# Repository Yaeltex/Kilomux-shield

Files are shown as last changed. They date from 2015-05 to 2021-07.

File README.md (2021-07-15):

# Kilomux Shield
This is the Kilomux Arduino Shield repository, developed by Yaeltex in collaboration with Jorge Crowe from El Laboratorio del Juguete, both located in Buenos Aires, Argentina.

Kilomux is an Arduino UNO shield which expands the number of inputs and outputs using multiplexers and 74HC595 ICs and allows MIDI communication via USB or hardware.

Kilomux Arduino Library has a [new repo](https://github.com/Yaeltex/kilomux-arduino-library) now!

It has 16 digital outputs (without PWM for the moment) and 32 analog/digital inputs, which can be used independently with the provided functions. 
The shield has also 4 free digital pins (2, 3, 12 and 13 in v1, and 10, 11, 12 and 13 in v2), intended to connect an ultrasonic sensor, a button and an LED for its activation.

In the repository you can find whole HIDUINO repository - the firmware to send MIDI via USB and allow PC to recognize the Arduino as a MIDI device. In the "hiduino-master" folder you can find a tutorial on how to recompile (and rename) the firmware and load it into the Arduino device.

For more info, go to our [wiki](https://wiki.yaeltex.com/?nocache=1#.C2.B7_Kilomux_Shield) (in Spanish, for now)

If you have any questions, suggestions or comments about the shield, email us at franco (at) yaeltex.com.ar or post in [Yaeltex's forum](http://forum.yaeltex.com)

Cheers!

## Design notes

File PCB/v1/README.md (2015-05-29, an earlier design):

Para ver la lista de materiales entra al siguiente enlace:

https://cdn.rawgit.com/Yaeltex/KiloMux-Shield/master/PCB/KILO_MUX_SHIELD%20v1_bom.html

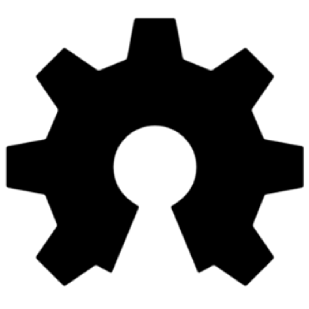
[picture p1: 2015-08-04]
PCB/v2/IMG serigrafia/OSH.bmp

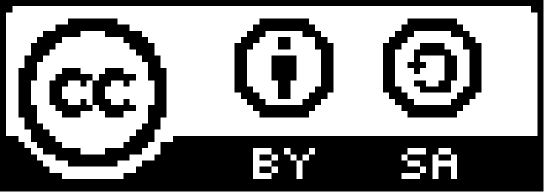
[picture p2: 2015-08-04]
PCB/v2/IMG serigrafia/CC-BY-SA bw2.bmp

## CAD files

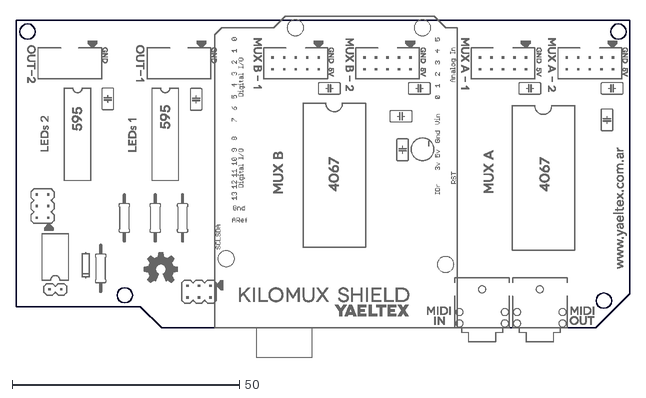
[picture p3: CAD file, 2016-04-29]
PCB/v2/Eagle/KilomuxV2.dxf
135.0 x 75.1

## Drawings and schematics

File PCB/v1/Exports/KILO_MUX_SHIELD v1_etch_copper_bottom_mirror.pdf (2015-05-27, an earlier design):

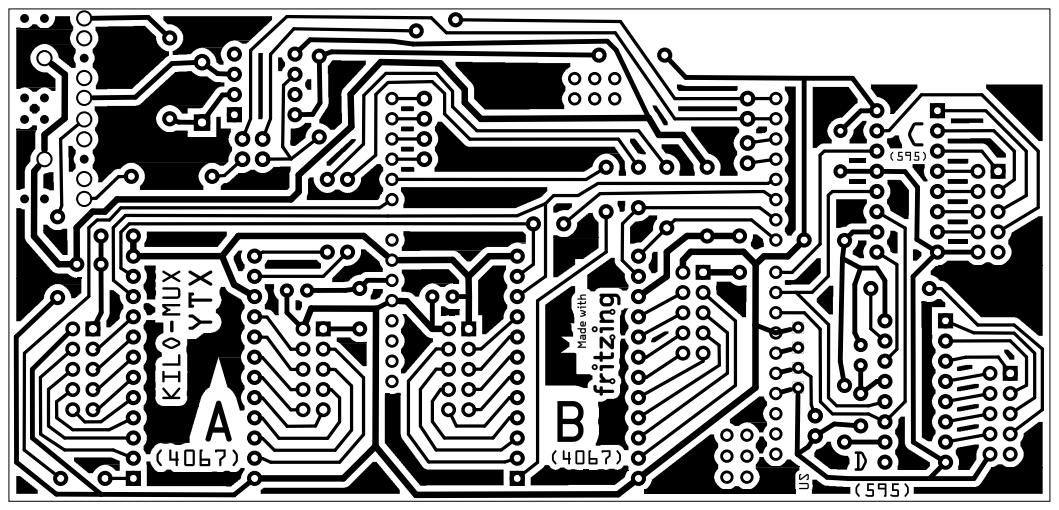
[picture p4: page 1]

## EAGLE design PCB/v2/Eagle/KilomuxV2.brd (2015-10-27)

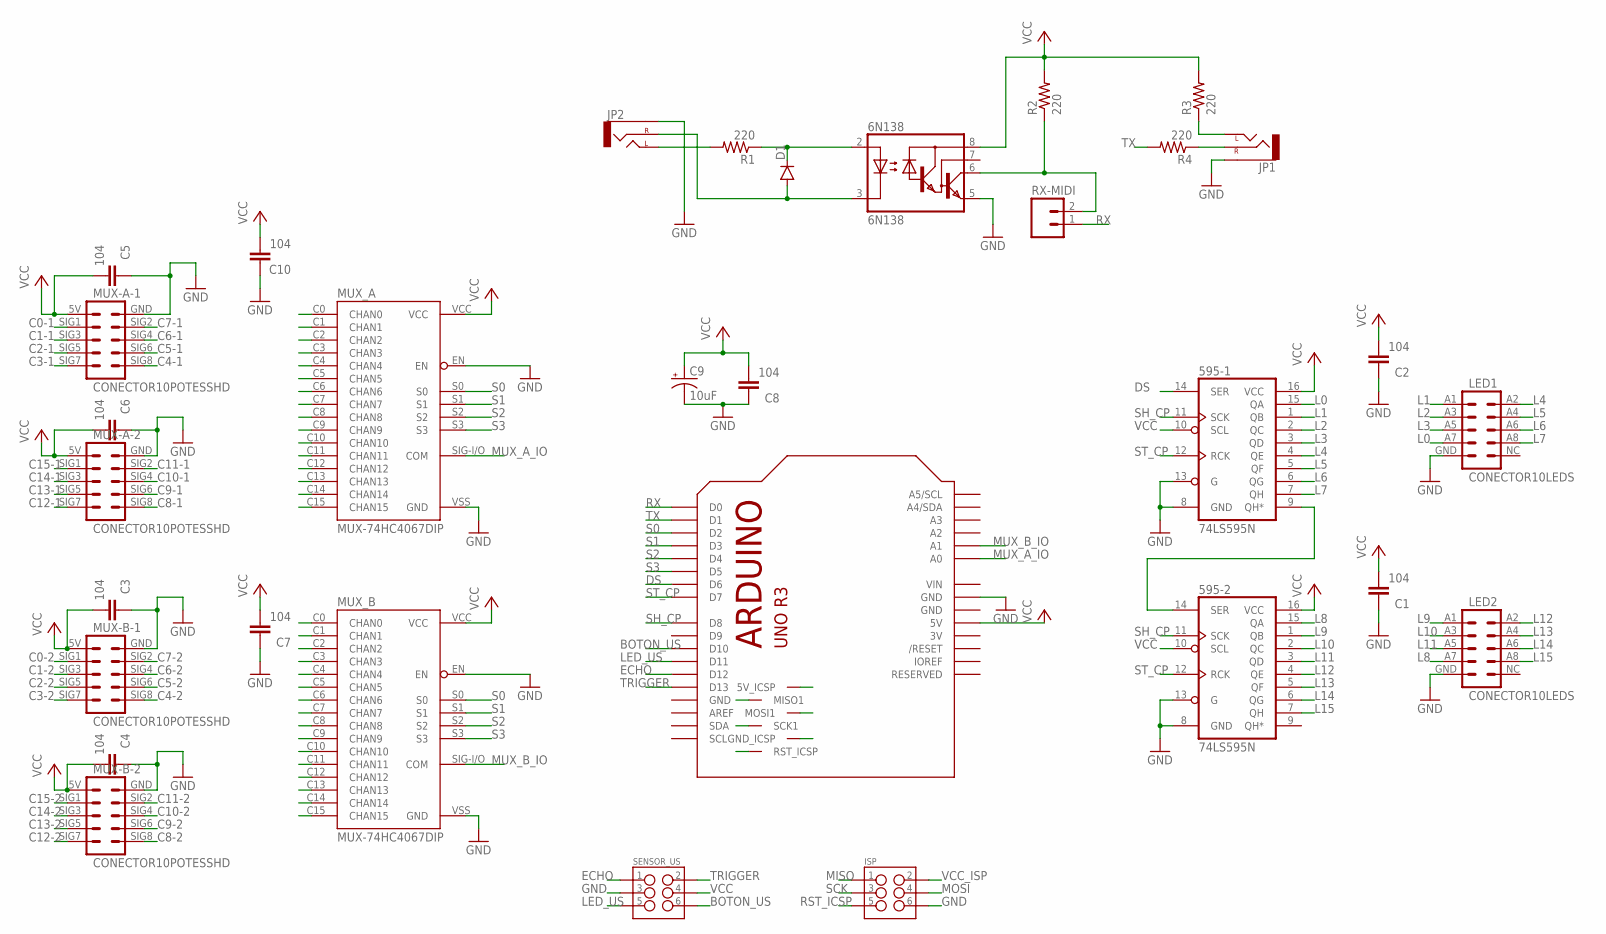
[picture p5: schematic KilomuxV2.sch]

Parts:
6N138: 6N138; DIL08
595-1, 595-2: 74LS595N; DIL16
C1, C2, C3, C4, C5, C6, C7, C8, C10: 104; C025-025X050
C9: 10uF; CPOL-RADIAL-10UF-25V
D1: DIODE1N4148; DIODE-1N4148
ISP: M03X2NO_SILK; HEADER-2X3-MALE
JP1, JP2: AUDIO-JACKPTH; AUDIO-JACK
LED1, LED2: CONECTOR10LEDS; HEADER-2X5-MALE-LEDS
M1: ARDUINO_R3_ICSP; ARDUINOR3_ICSP
MUX-A-1, MUX-A-2: CONECTOR10POTESSHD; HEADER-2X3-MALE-POTES
MUX-B-1, MUX-B-2: CONECTOR10POTESSHD; HEADER-2X3-MALE-POTES
MUX_A: MUX-74HC4067DIP; DIL24
MUX_B: MUX-74HC4067DIP; DIL24
R1, R2, R3, R4: 220; 0207/10
RX-MIDI: M02PTH; 1X02
SENSOR_US: M03X2NO_SILK; HEADER-2X3-MALE

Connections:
3V: M1.3V
BOTON_US: M1.D10, SENSOR_US.6
C0-1: MUX-A-1.SIG1, MUX_A.C0 (CHAN0)
C0-2: MUX-B-1.SIG1, MUX_B.C0 (CHAN0)
C1-1: MUX-A-1.SIG3, MUX_A.C1 (CHAN1)
C1-2: MUX-B-1.SIG3, MUX_B.C1 (CHAN1)
C2-1: MUX-A-1.SIG5, MUX_A.C2 (CHAN2)
C2-2: MUX-B-1.SIG5, MUX_B.C2 (CHAN2)
C3-1: MUX-A-1.SIG7, MUX_A.C3 (CHAN3)
C3-2: MUX-B-1.SIG7, MUX_B.C3 (CHAN3)
C4-1: MUX-A-1.SIG8, MUX_A.C4 (CHAN4)
C4-2: MUX-B-1.SIG8, MUX_B.C4 (CHAN4)
C5-1: MUX-A-1.SIG6, MUX_A.C5 (CHAN5)
C5-2: MUX-B-1.SIG6, MUX_B.C5 (CHAN5)
C6-1: MUX-A-1.SIG4, MUX_A.C6 (CHAN6)
C6-2: MUX-B-1.SIG4, MUX_B.C6 (CHAN6)
C7-1: MUX-A-1.SIG2, MUX_A.C7 (CHAN7)
C7-2: MUX-B-1.SIG2, MUX_B.C7 (CHAN7)
C8-1: MUX-A-2.SIG8, MUX_A.C8 (CHAN8)
C8-2: MUX-B-2.SIG8, MUX_B.C8 (CHAN8)
C9-1: MUX-A-2.SIG6, MUX_A.C9 (CHAN9)
C9-2: MUX-B-2.SIG6, MUX_B.C9 (CHAN9)
C10-1: MUX-A-2.SIG4, MUX_A.C10 (CHAN10)
C10-2: MUX-B-2.SIG4, MUX_B.C10 (CHAN10)
C11-1: MUX-A-2.SIG2, MUX_A.C11 (CHAN11)
C11-2: MUX-B-2.SIG2, MUX_B.C11 (CHAN11)
C12-1: MUX-A-2.SIG7, MUX_A.C12 (CHAN12)
C12-2: MUX-B-2.SIG7, MUX_B.C12 (CHAN12)
C13-1: MUX-A-2.SIG5, MUX_A.C13 (CHAN13)
C13-2: MUX-B-2.SIG5, MUX_B.C13 (CHAN13)
C14-1: MUX-A-2.SIG3, MUX_A.C14 (CHAN14)
C14-2: MUX-B-2.SIG3, MUX_B.C14 (CHAN14)
C15-1: MUX-A-2.SIG1, MUX_A.C15 (CHAN15)
C15-2: MUX-B-2.SIG1, MUX_B.C15 (CHAN15)
DS: 595-1.14 (SER), M1.D6
ECHO: M1.D12, SENSOR_US.1
GND: 6N138.5 (GND), 595-1.8 (GND), 595-1.13 (G), 595-2.8 (GND), 595-2.13 (G), C1.1, C2.1, C3.1, C4.1, C5.1, C6.1, C7.1, C8.1, C9.2 (-), C10.1, ISP.6, JP1.SLEEVE, JP2.SLEEVE, LED1.GND, LED2.GND, M1.GND, M1.GND@1 (GND), M1.GND@2 (GND), M1.GND@4 (GND_ICSP), MUX-A-1.GND, MUX-A-2.GND, MUX-B-1.GND, MUX-B-2.GND, MUX_A.EN, MUX_A.VSS (GND), MUX_B.EN, MUX_B.VSS (GND), SENSOR_US.3
L0: 595-1.15 (QA), LED1.A7 (POS7)
L1: 595-1.1 (QB), LED1.A1 (POS1)
L2: 595-1.2 (QC), LED1.A3 (POS3)
L3: 595-1.3 (QD), LED1.A5 (POS5)
L4: 595-1.4 (QE), LED1.A2 (POS2)
L5: 595-1.5 (QF), LED1.A4 (POS4)
L6: 595-1.6 (QG), LED1.A6 (POS6)
L7: 595-1.7 (QH), LED1.A8 (POS8)
L8: 595-2.15 (QA), LED2.A7 (POS7)
L9: 595-2.1 (QB), LED2.A1 (POS1)
L10: 595-2.2 (QC), LED2.A3 (POS3)
L11: 595-2.3 (QD), LED2.A5 (POS5)
L12: 595-2.4 (QE), LED2.A2 (POS2)
L13: 595-2.5 (QF), LED2.A4 (POS4)
L14: 595-2.6 (QG), LED2.A6 (POS6)
L15: 595-2.7 (QH), LED2.A8 (POS8)
LED_US: M1.D11, SENSOR_US.5
MISO: ISP.1, M1.MISO1
MOSI: ISP.4, M1.MOSI1
MUX_A_IO: M1.A0, MUX_A.SIG-I/O (COM)
MUX_B_IO: M1.A1, MUX_B.SIG-I/O (COM)
unnamed: JP2.TIP (LEFT), R1.2
unnamed: 6N138.3 (C), D1.A, JP2.RING (RIGHT)
unnamed: 6N138.2 (A), D1.C, R1.1
unnamed: 6N138.6 (VO), R2.1, RX-MIDI.2
unnamed: JP1.TIP (LEFT), R3.1
unnamed: JP1.RING (RIGHT), R4.1
RST_ICSP: ISP.5, M1.RESET_ICSP1 (RST_ICSP)
RX: M1.D0, RX-MIDI.1
S0: M1.D2, MUX_A.S0, MUX_B.S0
S1: M1.D3, MUX_A.S1, MUX_B.S1
S2: M1.D4, MUX_A.S2, MUX_B.S2
S3: M1.D5, MUX_A.S3, MUX_B.S3
SCK: ISP.3, M1.SCK1
SH_CP: 595-1.11 (SCK), 595-2.11 (SCK), M1.D8
SOUT: 595-1.9 (QH*), 595-2.14 (SER)
ST_CP: 595-1.12 (RCK), 595-2.12 (RCK), M1.D7
TRIGGER: M1.D13, SENSOR_US.2
TX: M1.D1, R4.2
VCC: 6N138.8 (VCC), 595-1.10 (SCL), 595-1.16 (VCC), 595-2.10 (SCL), 595-2.16 (VCC), C1.2, C2.2, C3.2, C4.2, C5.2, C6.2, C7.2, C8.2, C9.1 (+), C10.2, M1.5V, MUX-A-1.5V, MUX-A-2.5V, MUX-B-1.5V, MUX-B-2.5V, MUX_A.VCC, MUX_B.VCC, R2.2, R3.2, SENSOR_US.4
VCC_ISP: ISP.2, M1.5V_ICSP1 (5V_ICSP)
VIN: M1.VIN

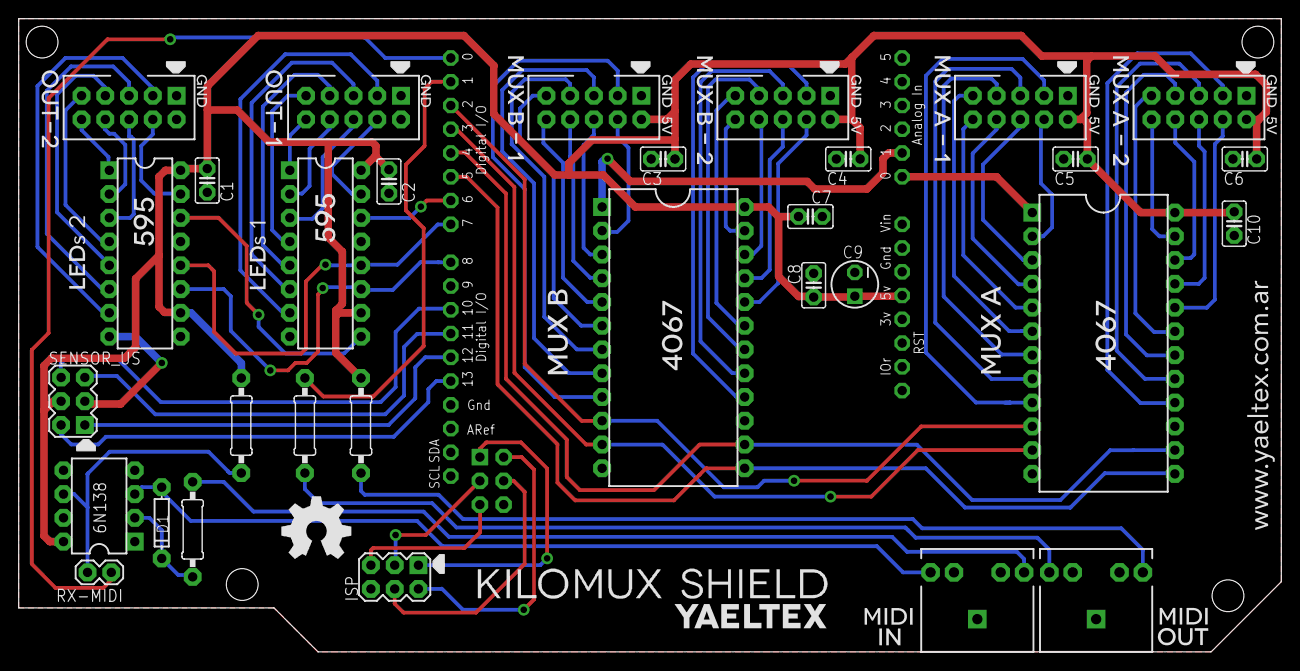
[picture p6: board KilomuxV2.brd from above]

Board: 2 copper layers, 135.0 x 67.7 mm, 32 parts (0 on the bottom side), 77 nets.

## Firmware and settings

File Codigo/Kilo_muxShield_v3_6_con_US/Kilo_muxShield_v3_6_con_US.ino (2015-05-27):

/*
Autor: Franco Grassano - YAELTEX
---
INFORMACIÓN DE LICENCIA
Kilo Mux Shield por Yaeltex se distribuye bajo una licencia
Creative Commons Atribución-CompartirIgual 4.0 Internacional - http://creativecommons.org/licenses/by-sa/4.0/
----
Código para el manejo de los integrados 74HC595 tomado de http://bildr.org/2011/02/74HC595/
Librería de multiplexado tomada de http://mayhewlabs.com/products/mux-shield-2

Este código fue desarrollado para el KILO MUX SHIELD (desde v3.6 hasta ---) de Yaeltex, apuntando al desarrollo de controladores MIDI.
Está preparado para manejar 2 registros de desplazamiento 74HC595 conectados en cadena (16 salidas digitales en total),
y 2 multiplexores CD4067 de 16 canales cada uno (16 entradas analógicas, y 16 entradas digitales), pero es expandible en el
caso de utilizar hardware diferente. Para ello se modifican los "define" NUM_MUX, NUM_CANALES_MUX y NUM_595s.

Para las entradas analógicas, por cuestiones de ruido se recomienda usar potenciómetros o sensores con buena estabilidad, y en
lo posible con valores cercanos o menores a 10 Kohm.

Para debuggear con Serial se deben comentar las lineas 
216 - MIDI.begin(MIDI_CHANNEL_OMNI;
222 - leer_MIDI();
428 - enviarControlChangeMidi(nota);
445 - enviarNoteMidi(nota, NOTE_ON);
450 - enviarNoteMidi(nota, NOTE_OFF);
    - MIDI.sendControlChange(CC_US_MIDI, ccSensorValue, CANAL_MIDI_CC);
          

Y se deben sacar los comentarios de las lineas 
217 - Serial.begin(VELOCIDAD_SERIAL);       // Se inicializa la comunicación serial.
223 - encender_leds_serial();
429 - enviarControlChangeSerial(nota);  
446 - enviarNoteSerial(nota, NOTE_ON);  
451 - enviarNoteSerial(nota, NOTE_ON);  
    - Serial.print("Sensor Ultrasonico CC: "); Serial.print(CC_US_MIDI); Serial.print("  Valor: "); Serial.print(ccSensorValue);
*/

#include <NewPing.h>
#include <MIDI.h>
#include <midi_Defs.h>
#include <midi_Namespace.h>
#include <midi_Settings.h>
#include <MuxShield.h>

#define NUM_MUX 2                                  // Número de multiplexores a direccionar
#define NUM_CANALES_MUX 16                         // Número de canales en cada mux

#define MUX_A 0
#define MUX_B 1
#define MUX_A_ENTRADA A0                           // Pin analógico por dónde se lee el MUX A
#define MUX_B_ENTRADA A1                           // Pin analógico por dónde se lee el MUX B

#define MUX_DIGITAL   MUX_A                        // CAMBIAR SEGÚN APLICACIÓN
#define MUX_ANALOGICO MUX_B                        // CAMBIAR SEGÚN APLICACIÓN

#define ENTRADA_DIGITAL   MUX_A_ENTRADA            // CAMBIAR SEGÚN APLICACIÓN -  Multiplexor con entradas digitales
#define ENTRADA_ANALOGICA MUX_B_ENTRADA            // CAMBIAR SEGÚN APLICACIÓN - Multiplexor con entradas analógicas

#define NUM_595s 2                                 // Número de integrados 74HC595
#define NUM_LEDS NUM_595s*8                        // Número de LEDs en total, NO CAMBIAR

// Estos valores dependen de como están cableados los botones en el controlador
// FIJOS - NO TOCAR!!!
#define NOTA_0_HW  0
#define NOTA_1_HW  1
#define NOTA_2_HW  2
#define NOTA_3_HW  3
#define NOTA_4_HW  4
#define NOTA_5_HW  5
#define NOTA_6_HW  6
#define NOTA_7_HW  7
#define NOTA_8_HW  8
#define NOTA_9_HW  9
#define NOTA_10_HW 10
#define NOTA_11_HW 11
#define NOTA_12_HW 12
#define NOTA_13_HW 13
#define NOTA_14_HW 14
#define NOTA_15_HW 15

// Estos son los valores de notas que se quieren recibir en la aplicación DAW.
// AJUSTABLES SEGÚN APLICACIÓN
#define NOTA_0_MIDI  0
#define NOTA_1_MIDI  1
#define NOTA_2_MIDI  2  
#define NOTA_3_MIDI  3
#define NOTA_4_MIDI  4
#define NOTA_5_MIDI  5
#define NOTA_6_MIDI  6
#define NOTA_7_MIDI  7
#define NOTA_8_MIDI  8
#define NOTA_9_MIDI  9
#define NOTA_10_MIDI 10
#define NOTA_11_MIDI 11
#define NOTA_12_MIDI 12
#define NOTA_13_MIDI 13
#define NOTA_14_MIDI 14
#define NOTA_15_MIDI 15

// Estos valores dependen de como están cableadas las entradas analógicas en el controlador
// FIJOS - NO TOCAR!!!
#define CC_0_HW  0
#define CC_1_HW  1
#define CC_2_HW  2
#define CC_3_HW  3
#define CC_4_HW  4
#define CC_5_HW  5
#define CC_6_HW  6
#define CC_7_HW  7
#define CC_8_HW  8
#define CC_9_HW  9
#define CC_10_HW 10
#define CC_11_HW 11
#define CC_12_HW 12
#define CC_13_HW 13
#define CC_14_HW 14
#define CC_15_HW 15

// Estos son los valores de Control Change que se quieren recibir en la aplicación DAW.
// AJUSTABLES SEGÚN APLICACIÓN
#define CC_0_MIDI  0
#define CC_1_MIDI  1
#define CC_2_MIDI  2
#define CC_3_MIDI  3
#define CC_4_MIDI  4
#define CC_5_MIDI  5
#define CC_6_MIDI  6
#define CC_7_MIDI  7
#define CC_8_MIDI  8
#define CC_9_MIDI  9
#define CC_10_MIDI 10
#define CC_11_MIDI 11
#define CC_12_MIDI 12
#define CC_13_MIDI 13
#define CC_14_MIDI 14
#define CC_15_MIDI 15

#define CC_US_MIDI 16

// Estos son los identificadores de cada LED en hardware.
// FIJOS - NO TOCAR!!!
#define N_LED_HW_0 0
#define N_LED_HW_1 1
#define N_LED_HW_2 2
#define N_LED_HW_3 3
#define N_LED_HW_4 4
#define N_LED_HW_5 5
#define N_LED_HW_6 6
#define N_LED_HW_7 7
#define N_LED_HW_8 8
#define N_LED_HW_9 9
#define N_LED_HW_10 10
#define N_LED_HW_11 11
#define N_LED_HW_12 12
#define N_LED_HW_13 13
#define N_LED_HW_14 14
#define N_LED_HW_15 15

// Estos son los valores de notas a los que responde cada LED. Deben estar apareados los LEDs que sean indicadores de botones.
// AJUSTABLES SEGÚN APLICACIÓN
#define N_LED_MIDI_0 0
#define N_LED_MIDI_1 1
#define N_LED_MIDI_2 2
#define N_LED_MIDI_3 3
#define N_LED_MIDI_4 4
#define N_LED_MIDI_5 5
#define N_LED_MIDI_6 6
#define N_LED_MIDI_7 7
#define N_LED_MIDI_8 8
#define N_LED_MIDI_9 9
#define N_LED_MIDI_10 10
#define N_LED_MIDI_11 11
#define N_LED_MIDI_12 12
#define N_LED_MIDI_13 13
#define N_LED_MIDI_14 14
#define N_LED_MIDI_15 15

#define NOTE_ON   127
#define NOTE_OFF  0

#define CANAL_MIDI_NOTES  1                              // DEFINIR CANAL MIDI A UTILIZAR
#define CANAL_MIDI_CC     1                              // DEFINIR CANAL MIDI A UTILIZAR
#define CANAL_MIDI_LEDS   1                              // DEFINIR CANAL MIDI A UTILIZAR

#define UMBRAL_RUIDO        1                      // Ventana de ruido para las entradas analógicas. Si entrada < entrada+umbral o 
                                                   //                                                   entrada > entrada-umbral descarta la lectura.
#define INTERVALO_LEDS      300                    // Intervalo de intermitencia
#define VELOCITY_LIM_TITILA 64                     // Limite de velocity para definir parpadeo - 0            - APAGADO
                                                   //                                            1 a LIMITE   - TITILA
                                                   //                                            LIMITE a 127 - ENCENDIDO
// DEFINES PARA SENSOR ULTRASONICO                                                 
// FIJOS - NO CAMBIAR!!!
#define TRIGGER_PIN          13        // Pin de arduino conectado al pin de trigger del sensor
#define ECHO_PIN             12        // Pin de arduino conectado al pin de echo del sensor.
#define PIN_BOTON_ACT_US     2
#define PIN_LED_ACT_US       3
#define MAX_US               MAX_DISTANCIA*US_ROUNDTRIP_CM   // Maximo tiempo en microsegundos que dura el pulso en retornar
#define MIN_US               MIN_DISTANCIA*US_ROUNDTRIP_CM   // Minimo tiempo en microsegundos que dura el pulso en retornar
// AJUSTABLES
#define MAX_DISTANCIA        30        // Maxima distancia que se desea medir (en centimetros). El sensor mide hasta 400-500cm.
#define MIN_DISTANCIA        2         // Minima distancia que se desea medir (en centimetros). El sensor mide desde 1cm.
#define DELAY_ULTRAS         15        // Delay entre dos pings de
#define UMBRAL_DIFERENCIA_US 80 
#define FILTRO_US            3
                                                   
#define VELOCIDAD_SERIAL 115200                    // Velocidad de transferencia (bits/seg) de la comunicación serial

NewPing sensorUS(TRIGGER_PIN, ECHO_PIN, MAX_DISTANCIA); // Instancia de NewPing para el sensor US.
int ccSensorValuePrev[FILTRO_US];

MuxShield muxShield;                               // Objeto de la clase MuxShield, para leer los multiplexores

// Variables para los registros de desplazamiento
const int dataPin = 8;                             // Pin de datos (DS) conectado al pin 14 del 74HC595
const int latchPin = 9;                            // Pin de latch (ST_CP) conectado al pin 12 del 74HC595
const int clockPin = 10;                           // Pin de clock (SH_CP) conectado al pin 11 del 74HC595
boolean registros[NUM_LEDS];                       // Estado de los LEDs (HIGH - 1 o LOW - 0)
boolean leds_que_titilan[NUM_LEDS];                // Si está en 1, el LED titila. Si está en 0, no titila

// Datos analógicos
byte velocity[NUM_MUX][NUM_CANALES_MUX];               // Variable de 1 byte que guarda la velocity actual de cada canal
byte velocityPrev[NUM_MUX][NUM_CANALES_MUX];           // Variable de 1 byte que guarda la velocity anterior de cada canal


// Contadores, flags
int mux, canal;                           // Contadores para recorrer los multiplexores
bool tiempo_on = 0;                       // Tiempo que llevan encendidos los leds, para el parpadeo
unsigned int anteriorMillis = 0;          // Variable para guardar ms

void setup() {
  // Setear pines de salida
  pinMode(latchPin, OUTPUT);
  pinMode(dataPin, OUTPUT);
  pinMode(clockPin, OUTPUT);

  pinMode(PIN_LED_ACT_US, OUTPUT);         // LED indicador para el sensor de distancia
  pinMode(PIN_BOTON_ACT_US,INPUT_PULLUP);  // Botón de activación para el sensor de distancia
  
  pinMode(ENTRADA_DIGITAL, INPUT);                // Estas dos líneas setean el pin analógico que recibe las entradas digitales como pin digital y
  digitalWrite(ENTRADA_DIGITAL, HIGH);            // setea el resistor de Pull-Up en el mismo

  // Guardar cantidad de ms desde el encendido
  anteriorMillis = millis();

  for (mux = 0; mux < NUM_MUX; mux++) {                // Setear todos los velocity a 0
    for (canal = 0; canal < NUM_CANALES_MUX; canal++) {
      velocity[mux][canal] = 0;
      velocityPrev[mux][canal] = 0;
    }
  }

  clearRegisters();                             // Se limpia el array registros (todos a LOW)
  writeRegisters();                             // Se envían los datos al 595
  // COMENTAR LA SIGUIENTE LINEA PARA DEBUGGEAR CON SERIAL ///////////////////////////////////////////////////////////////////////
//  MIDI.begin(MIDI_CHANNEL_OMNI); MIDI.turnThruOff();  // Se inicializa la comunicación MIDI.
                                                      // Por default, la librería de Arduino MIDI tiene el THRU en ON, y NO QUEREMOS ESO!
                                                      
  // DESCOMENTAR LA SIGUIENTE LINEA PARA DEBUGGEAR CON SERIAL ///////////////////////////////////////////////////////////////////////                                                      
  Serial.begin(VELOCIDAD_SERIAL);                  // Se inicializa la comunicación serial. Descomentar para usar con Hairless MID
}

void loop() {  
  // COMENTAR LA SIGUIENTE LINEA PARA DEBUGGEAR CON SERIAL ///////////////////////////////////////////////////////////////////////
//   leer_MIDI();
  // DESCOMENTAR LA SIGUIENTE LINEA PARA DEBUGGEAR CON SERIAL ///////////////////////////////////////////////////////////////////////
  encender_leds_serial();
  if (millis() - anteriorMillis > INTERVALO_LEDS)          // Si transcurrieron más de X ms desde la ultima actualización,
    titilarLeds();
  leerEntradas();
  leerUltrasonico();
}

// Lee el canal midi, note y velocity, y actualiza el estado de los leds.
void leer_MIDI(void) {
  // COMENTAR PARA DEBUGGEAR CON SERIAL ///////////////////////////////////////////////////////////////////////
  if (MIDI.read(CANAL_MIDI_LEDS)) {         // ¿Llegó un mensaje MIDI?
    byte led_number = MIDI.getData1();  // Capturo la nota
    byte led_vel = MIDI.getData2();
    switch (MIDI.getType())                  // Identifica que tipo de mensaje llegó (NoteOff, NoteOn, AfterTouchPoly, ControlChange, ProgramChange, AfterTouchChannel, PitchBend, SystemExclusive)
    {
      case midi::NoteOn:                       // En caso que sea NoteOn,
        if (led_vel > VELOCITY_LIM_TITILA) {     // Si la velocity es un valor entre LIMITE y 127, el led no parpadea
          switch(led_number){
            case N_LED_MIDI_0:
              setLed_595(N_LED_HW_0, HIGH); leds_que_titilan[N_LED_HW_0] = 0; break;      // Encender el LED correspondiente y no dejar que titile
            case N_LED_MIDI_1:
              setLed_595(N_LED_HW_1, HIGH); leds_que_titilan[N_LED_HW_1] = 0; break;            
            case N_LED_MIDI_2:
              setLed_595(N_LED_HW_2, HIGH); leds_que_titilan[N_LED_HW_2] = 0; break;            
            case N_LED_MIDI_3:
              setLed_595(N_LED_HW_3, HIGH); leds_que_titilan[N_LED_HW_3] = 0; break;            
            case N_LED_MIDI_4:
              setLed_595(N_LED_HW_4, HIGH); leds_que_titilan[N_LED_HW_4] = 0; break;            
            case N_LED_MIDI_5:
              setLed_595(N_LED_HW_5, HIGH); leds_que_titilan[N_LED_HW_5] = 0; break;            
            case N_LED_MIDI_6:
              setLed_595(N_LED_HW_6, HIGH); leds_que_titilan[N_LED_HW_6] = 0; break;            
            case N_LED_MIDI_7:
              setLed_595(N_LED_HW_7, HIGH); leds_que_titilan[N_LED_HW_7] = 0; break;            
            case N_LED_MIDI_8:
              setLed_595(N_LED_HW_8, HIGH); leds_que_titilan[N_LED_HW_8] = 0; break;            
            case N_LED_MIDI_9:
              setLed_595(N_LED_HW_9, HIGH); leds_que_titilan[N_LED_HW_9] = 0; break;            
            case N_LED_MIDI_10:
              setLed_595(N_LED_HW_10, HIGH); leds_que_titilan[N_LED_HW_10] = 0; break;           
            case N_LED_MIDI_11:
              setLed_595(N_LED_HW_11, HIGH); leds_que_titilan[N_LED_HW_11] = 0; break;           
            case N_LED_MIDI_12:
              setLed_595(N_LED_HW_12, HIGH); leds_que_titilan[N_LED_HW_12] = 0; break;           
            case N_LED_MIDI_13:
              setLed_595(N_LED_HW_13, HIGH); leds_que_titilan[N_LED_HW_13] = 0; break;           
            case N_LED_MIDI_14:
              setLed_595(N_LED_HW_14, HIGH); leds_que_titilan[N_LED_HW_14] = 0; break;           
            case N_LED_MIDI_15:
              setLed_595(N_LED_HW_15, HIGH); leds_que_titilan[N_LED_HW_15] = 0; break;            // Encender el LED correspondiente              
            default: break;  
          }
        }
        else if (led_vel > 0 && led_vel <= VELOCITY_LIM_TITILA)     // Si la velocity es mayor a cero, y menor a LIMITE,
          switch(led_number){
            case N_LED_MIDI_0:
              leds_que_titilan[N_LED_HW_0] = 1; break;      // Encender el LED correspondiente y hacer que titile
            case N_LED_MIDI_1:
              leds_que_titilan[N_LED_HW_1] = 1; break;            
            case N_LED_MIDI_2:
              leds_que_titilan[N_LED_HW_2] = 1; break;            
            case N_LED_MIDI_3:
              leds_que_titilan[N_LED_HW_3] = 1; break;            
            case N_LED_MIDI_4:
              leds_que_titilan[N_LED_HW_4] = 1; break;            
            case N_LED_MIDI_5:
              leds_que_titilan[N_LED_HW_5] = 1; break;            
            case N_LED_MIDI_6:
              leds_que_titilan[N_LED_HW_6] = 1; break;            
            case N_LED_MIDI_7:
              leds_que_titilan[N_LED_HW_7] = 1; break;            
            case N_LED_MIDI_8:
              leds_que_titilan[N_LED_HW_8] = 1; break;            
            case N_LED_MIDI_9:
              leds_que_titilan[N_LED_HW_9] = 1; break;            
            case N_LED_MIDI_10:
              leds_que_titilan[N_LED_HW_10] = 1; break;           
            case N_LED_MIDI_11:
              leds_que_titilan[N_LED_HW_11] = 1; break;           
            case N_LED_MIDI_12:
              leds_que_titilan[N_LED_HW_12] = 1; break;           
            case N_LED_MIDI_13:
              leds_que_titilan[N_LED_HW_13] = 1; break;           
            case N_LED_MIDI_14:
              leds_que_titilan[N_LED_HW_14] = 1; break;           
            case N_LED_MIDI_15:
              leds_que_titilan[N_LED_HW_15] = 1; break;            // Encender el LED correspondiente              
            default: break;  
          }          
        else {                                                      // Si las anteriores no se cumplen, entonces es velocity = 0, es decir NoteOff,
          switch(led_number){
            case N_LED_MIDI_0:
              setLed_595(N_LED_HW_0, LOW); leds_que_titilan[N_LED_HW_0] = 0; break;      // Encender el LED correspondiente y no dejar que titile
            case N_LED_MIDI_1:
              setLed_595(N_LED_HW_1, LOW); leds_que_titilan[N_LED_HW_1] = 0; break;            
            case N_LED_MIDI_2:
              setLed_595(N_LED_HW_2, LOW); leds_que_titilan[N_LED_HW_2] = 0; break;            
            case N_LED_MIDI_3:
              setLed_595(N_LED_HW_3, LOW); leds_que_titilan[N_LED_HW_3] = 0; break;            
            case N_LED_MIDI_4:
              setLed_595(N_LED_HW_4, LOW); leds_que_titilan[N_LED_HW_4] = 0; break;            
            case N_LED_MIDI_5:
              setLed_595(N_LED_HW_5, LOW); leds_que_titilan[N_LED_HW_5] = 0; break;            
            case N_LED_MIDI_6:
              setLed_595(N_LED_HW_6, LOW); leds_que_titilan[N_LED_HW_6] = 0; break;            
            case N_LED_MIDI_7:
              setLed_595(N_LED_HW_7, LOW); leds_que_titilan[N_LED_HW_7] = 0; break;            
            case N_LED_MIDI_8:
              setLed_595(N_LED_HW_8, LOW); leds_que_titilan[N_LED_HW_8] = 0; break;            
            case N_LED_MIDI_9:
              setLed_595(N_LED_HW_9, LOW); leds_que_titilan[N_LED_HW_9] = 0; break;            
            case N_LED_MIDI_10:
              setLed_595(N_LED_HW_10, LOW); leds_que_titilan[N_LED_HW_10] = 0; break;           
            case N_LED_MIDI_11:
              setLed_595(N_LED_HW_11, LOW); leds_que_titilan[N_LED_HW_11] = 0; break;           
            case N_LED_MIDI_12:
              setLed_595(N_LED_HW_12, LOW); leds_que_titilan[N_LED_HW_12] = 0; break;           
            case N_LED_MIDI_13:
              setLed_595(N_LED_HW_13, LOW); leds_que_titilan[N_LED_HW_13] = 0; break;           
            case N_LED_MIDI_14:
              setLed_595(N_LED_HW_14, LOW); leds_que_titilan[N_LED_HW_14] = 0; break;           
            case N_LED_MIDI_15:
              setLed_595(N_LED_HW_15, LOW); leds_que_titilan[N_LED_HW_15] = 0; break;            // Encender el LED correspondiente              
            default: break;  
          }
        }
        break;
      default:
        break;
    }
  }
  // FIN COMENTARIO ///////////////////////////////////////////////////////////////////////////////////////////
}

void encender_leds_serial(void){
// EL DEBUG FUNCIONA ENVIANDO DESDE EL TERMINAL SERIE UN NUMERO DEL 0-9 O UNA LETRA DE a-f O DE A-F (10-15) QUE CORRESPONDE AL LED QUE QUEREMOS QUE CAMBIE DE ESTADO
  // CADA VEZ QUE LLEGA EL NUMERO, SE CAMBIA DE UN ESTADO AL SIGUIENTE
  // APAGADO -> TITILANDO -> ENCENDIDO -> APAGADO

  // DESCOMENTAR PARA DEBUGGEAR CON SERIAL ///////////////////////////////////////////////////////////////////////
    static unsigned int leds[NUM_LEDS] = {0,0,0,0,0,0,0,0,0,0,0,0,0,0,0,0};
    if (Serial.available()){                // ¿Llegó un mensaje Serial?
  
      byte led_number = Serial.read();  // Capturo la nota
      switch(led_number){
        case 'a': led_number = 10; break; case 'A': led_number = 10; break;
        case 'b': led_number = 11; break; case 'B': led_number = 11; break;
        case 'c': led_number = 12; break; case 'C': led_number = 12; break;
        case 'd': led_number = 13; break; case 'D': led_number = 13; break;
        case 'e': led_number = 14; break; case 'E': led_number = 14; break;
        case 'f': led_number = 15; break; case 'F': led_number = 15; break;
        case 'o': 
          for (int i = 0; i<NUM_LEDS; i++){
            setLed_595(i, HIGH);
          }
          delay(1000);
          for (int i = 0; i<NUM_LEDS; i++){
            setLed_595(i, LOW);
          }
          return;
        break;
        default: led_number %= 16; break;
      }
      leds[led_number]++;
      leds[led_number] %= 3;
      if (leds[led_number] == 0){
        setLed_595(led_number, LOW);                                // Apagar el LED correspondiente
        leds_que_titilan[led_number] = 0;                         // Actualizar el flag para que no titile más
        Serial.print("LED "); Serial.print(led_number); Serial.println(" apagado.");
      }
      else if (leds[led_number] == 1){
        leds_que_titilan[led_number] = 1;                         // Actualizar el flag para que titile
        Serial.print("LED "); Serial.print(led_number); Serial.println(" titilando.");
      }
      else if (leds[led_number] == 2){
        setLed_595(led_number, HIGH);                               // Encender el LED correspondiente
        leds_que_titilan[led_number] = 0;                         // Actualizar el flag para que no titile más
        Serial.print("LED "); Serial.print(led_number); Serial.println(" encendido.");
      }
  
    }
  // FIN COMENTARIO DEBUG ///////////////////////////////////////////////////////////////////////////////////////////
}
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

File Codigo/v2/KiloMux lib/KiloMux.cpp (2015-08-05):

/**
* Autor: Franco Grassano - YAELTEX
* ---
* INFORMACIÓN DE LICENCIA
* Kilo Mux Shield por Yaeltex se distribuye bajo una licencia
* Creative Commons Atribución-CompartirIgual 4.0 Internacional - http://creativecommons.org/licenses/by-sa/4.0/
* ----
* Código para el manejo de los integrados 74HC595 tomado de http://bildr.org/2011/02/74HC595/
* Librería de multiplexado (modificada) tomada de http://mayhewlabs.com/products/mux-shield-2
* Librería para el manejo del sensor de ultrasonido tomada de http://playground.arduino.cc/Code/NewPing
* 
* Este código fue desarrollado para el KILO MUX SHIELD desarrolado en conjunto por Yaeltex y el Laboratorio del Juguete, en Buenos Aires, Argentina, 
* apuntando al desarrollo de controladores MIDI con arduino.
* Está preparado para manejar 2 (expandible) registros de desplazamiento 74HC595 conectados en cadena (16 salidas digitales en total),
* y 2 multiplexores CD4067 de 16 canales cada uno (16 entradas analógicas, y 16 entradas digitales), pero es expandible en el
* caso de utilizar hardware diferente. Para ello se modifican los "define" NUM_MUX, NUM_CANALES_MUX y NUM_595s. 
* NOTA: Se modificó la librería MuxShield, para trabajar sólo con 1 o 2 multiplexores. Si se necesita usar más multiplexores, descargar la librería original.
* 
* Para las entradas analógicas, por cuestiones de ruido se recomienda usar potenciómetros o sensores con buena estabilidad, y con preferencia con valores 
* cercanos o menores a 10 Kohm.
* Agradecimientos:
*  - Jorge Crowe
*  - Lucas Leal
*  - Dimitri Diakopoulos
*/

//////////////////////////////////////////////////////////////////////////////////////////
// INICIALIZACIÓN ////////////////////////////////////////////////////////////////////////
//////////////////////////////////////////////////////////////////////////////////////////

void InitKiloMux(void) {
  // Setear pines de salida de los registro de desplazamiento 74HC595
  pinMode(latchPin, OUTPUT);                
  pinMode(dataPin, OUTPUT);
  pinMode(clockPin, OUTPUT);
  
#if defined(CON_ULTRASONIDO)
  pinMode(PIN_LED_ACT_US, OUTPUT);         // LED indicador para el sensor de distancia
  pinMode(PIN_BOTON_ACT_US,INPUT_PULLUP);  // Botón de activación para el sensor de distancia
#endif  

#if defined(ENTRADA_DIGITAL)                                                    
  pinMode(ENTRADA_DIGITAL, INPUT);                // Estas dos líneas setean el pin analógico que recibe las entradas digitales como pin digital y
  digitalWrite(ENTRADA_DIGITAL, HIGH);            // setea el resistor de Pull-Up en el mismo
#endif // endif ENTRADA_DIGITAL

  // Guardar cantidad de ms desde el encendido
  anteriorMillis = millis();
  
  // Setear todos las lecturas a 0
  for (mux = 0; mux < NUM_MUX; mux++) {                
    for (canal = 0; canal < NUM_CANALES_MUX; canal++) {
      lecturas[mux][canal] = 0;
      lecturasPrev[mux][canal] = 0;
    }
    #if defined(MUX_DIGITAL)
      if (mux == MUX_DIGITAL) estadoBoton[bancoActivo][canal] = 0;     
    #endif // endif MUX_DIGITAL
  }
  // Setear todos los leds a 0
  for (i = 0; i < BANCOS; i++) {                
    for (j = 0; j < NUM_LEDS_X_BANCO; j++) {
       estadoLeds[i][j] = LED_APAGADO;
       estadoBoton[i][j] = 0;
    }
    estadoShifter[i] = 0;
  }
  
  // Ésta función setea la velocidad de muestreo del conversor analógico digital.
  SetADCprescaler(PS_16);

  LimpiarRegistros595();                             // Se limpia el array registros (todos a LOW)
  EscribirRegistros595();                             // Se envían los datos al 595

#if defined(COMUNICACION_MIDI)
  MIDI.begin(MIDI_CHANNEL_OMNI); MIDI.turnThruOff();  // Se inicializa la comunicación MIDI.
                                                      // Por default, la librería de Arduino MIDI tiene el THRU en ON, y NO QUEREMOS ESO!
#elif defined(COMUNICACION_SERIAL)
  Serial.begin(VELOCIDAD_SERIAL);                  // Se inicializa la comunicación serial. 
#elif defined(HAIRLESS_MIDI)
  MIDI.begin(MIDI_CHANNEL_OMNI); MIDI.turnThruOff();  // Se inicializa la comunicación MIDI.
                                                      // Por default, la librería de Arduino MIDI tiene el THRU en ON, y NO QUEREMOS ESO!
  Serial.begin(VELOCIDAD_SERIAL);                  // Se inicializa la comunicación serial. 
#endif
}
//////////////////////////////////////////////////////////////////////////////////////////
// PROGRAMA PRINCIPAL ////////////////////////////////////////////////////////////////////
//////////////////////////////////////////////////////////////////////////////////////////
void loop() {
  // LECTURA DE DATOS POR CANAL MIDI O SERIAL //////////////////////////////
  #if defined(COMUNICACION_MIDI)|defined(HAIRLESS_MIDI)       
  LeerMidi();                          
  #elif defined(COMUNICACION_SERIAL)
  EncenderLedsSerial();
  #endif    //endif COMUNICACION 

  // LECTURA DE ENTRADAS ///////////////////////////////////////////////////
  // Esta función recorre las entradas de los multiplexores y envía datos MIDI si detecta cambios.  
  LeerEntradas();
  
  #if defined(CON_ULTRASONIDO)
  // Función que lee los datos que reporta el sensor ultrasónico, filtra y envía la información MIDI si hay cambios.
  LeerUltrasonico();
  #endif

  // ACTUALIZACIÓN DE SALIDAS //////////////////////////////////////////////
  if(cambioBanco || cambioEstadoLeds){
    ActualizarLeds();
    cambioBanco = 0; cambioEstadoLeds = 0;  
  }
  if (millis() - anteriorMillis > INTERVALO_LEDS)          // Si transcurrieron más de X ms desde la ultima actualización,
    TitilarLeds(); 
  ////////////////////////////////////////////////////////////////////////// 
}
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

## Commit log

2015-05-27 KiloMux Shield
    El KiloMux es un shield para Arduino UNO que expande la cantidad de
    entradas y salidas usando multiplexores e integrados 79HC595 y permite
    la comunicación via MIDI, ya sea por USB o por hardware.
    Se tienen 16 salidas digitales (por ahora sin PWM) y 32 entradas con la
    posibilidad de combinar 16 digitales y 16 analógicas o 32 analógicas o
    32 digitales. El shield tiene también libres los pines 2, 3, 12 y 13,
    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
    [BoardDeviceMap.cfg, BootloaderDeviceMap.cfg, KILO_MUX_SHIELD v1.fzz]
2015-05-27 Corrección en el PCB
    Se corrigió la posición del rectángulo en el PCB del KiloMux
    [KILO_MUX_SHIELD v1.fzz]
2015-05-27 Revert "KiloMux Shield"
    This reverts commit d45241305f9d1b27c13db9e6093eab8ca5d7117d.
    Conflicts:
    PCB/KILO_MUX_SHIELD v1.fzz
    [BoardDeviceMap.cfg, BootloaderDeviceMap.cfg, KILO_MUX_SHIELD v1.fzz]
2015-05-27 Upload de todos los archivos
    [BoardDeviceMap.cfg, BootloaderDeviceMap.cfg, KILO_MUX_SHIELD v1.fzz]
2015-05-27 Cambio de nombres
2015-05-27 Cambio de nombre
2015-05-27 mejora menor a la lectura del sensor ultrasonico
2015-05-28 Comunicacion por midi y sensor de ultrasonido por defecto
2015-05-28 define para Hairless midi
2015-05-28 Correción de comentarios
2015-05-28 Arreglado el problema con los defines
2015-05-28 Correcciones de codigo para compilacion y sensor de ultrasonido
2015-05-28 Añadida la BOM y correcciones en el PCB
    [KILO_MUX_SHIELD v1.fzz]
2015-05-28 Correccion en el codigo, los includes no dependen del tipo de comunicacion
2015-05-29 Link para lista de materiales
2015-05-29 Cambio de titulo
2015-05-29 Actualizacion de la visualizacion HTML
2015-06-09 Mejorada la funcion esRuido, y añadida la opcion de modo TOGGLE a los botones
2015-06-16 Mejorada la funcion de filtrado de ruido
2015-06-17 Añadida la funcionalidad de hasta 3 shifters. Se apagan los leds si se recibe cualquier NoteOff, ademas de si se recibe NoteOn con velocity 0
2015-06-17 Agregada arduino_midi.hex
2015-08-04 correccion de errores de tipeo
2015-08-04 Agregada la version 2 del KiloMux Shield
    [KILO_MUX_SHIELD v1.fzz, KiloMuxV2.brd, KiloMuxV2.sch]
2015-08-05 Corregidos los pines libres de la v1 y v2
2015-08-05 Agregado el codigo y las librerias necesarias para la v2 del KiloMux Shield
    [BoardDeviceMap.cfg, BootloaderDeviceMap.cfg]
2015-08-05 Eliminado el codigo viejo
2015-08-06 Cambio de nombre de carpeta
2015-08-06 Codigo de arduino para la v2 del KiloMux
2015-08-06 Reestructuracion de la carpeta Codigo
2015-08-06 Reestructuracion de la carpeta
    [BoardDeviceMap.cfg, BootloaderDeviceMap.cfg]
2015-08-06 Añadida la version de codigo para la v1 del KiloMux
    [BoardDeviceMap.cfg, BootloaderDeviceMap.cfg]
2015-08-06 Reubicacion del proyecto hiduino
    [BoardDeviceMap.cfg, BootloaderDeviceMap.cfg]
2015-08-07 Añadida datasheet del sensor HC-SR04
2015-09-19 Some names changed to english
    [BoardDeviceMap.cfg, BootloaderDeviceMap.cfg]
2015-10-27 Replaced and corrected label orientation for digital outputs
    [KiloMuxV2.brd, KiloMuxV2.sch]
2016-02-04 Rename Arduino Library -> Arduino Code
    [BoardDeviceMap.cfg, BootloaderDeviceMap.cfg]
2016-02-16 Revised library examples, and added spanish version for ultrasonic
2016-02-16 Corrected schematic
2016-02-19 Removed old PCB
    [KILO_MUX_SHIELD v1.fzz, KiloMuxV2.brd, KiloMuxV2.sch]
2016-02-19 Added new PCB folder
    [KILO_MUX_SHIELD v1.fzz, KilomuxV2.brd, KilomuxV2.sch]
2016-03-09 Added example LedMatrix
2016-03-10 Añadida versión en español de ejemplo con matriz de LEDs
2016-04-29 Añadido v3 del controlador midi con el Kilomux
    [KILO_MUX_SHIELD v1.fzz, KilomuxV2.dxf]
2016-04-29 Actualizado el README
2016-05-02 Se agrega al codigo la opcion de activar y desactivar entradas, y elegir si son analogicas o digitales
2017-03-30 Moved hiduino folder
    [BoardDeviceMap.cfg, BootloaderDeviceMap.cfg]
2017-03-31 Removed hiduino rep copy and added a mocolufa hex renamed Kilomux
    [BoardDeviceMap.cfg, BootloaderDeviceMap.cfg]
